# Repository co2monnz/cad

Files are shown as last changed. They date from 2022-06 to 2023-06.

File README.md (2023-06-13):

# co2mon.nz Ventilation Monitor Cases

Inspired by https://github.com/oseiler2/CO2Monitor

## Description

This respoitory contains case designs for CO2 based ventilation monitors
intended for fixed (wall-mounted) use in standard residential, office and
retail type spaces. 

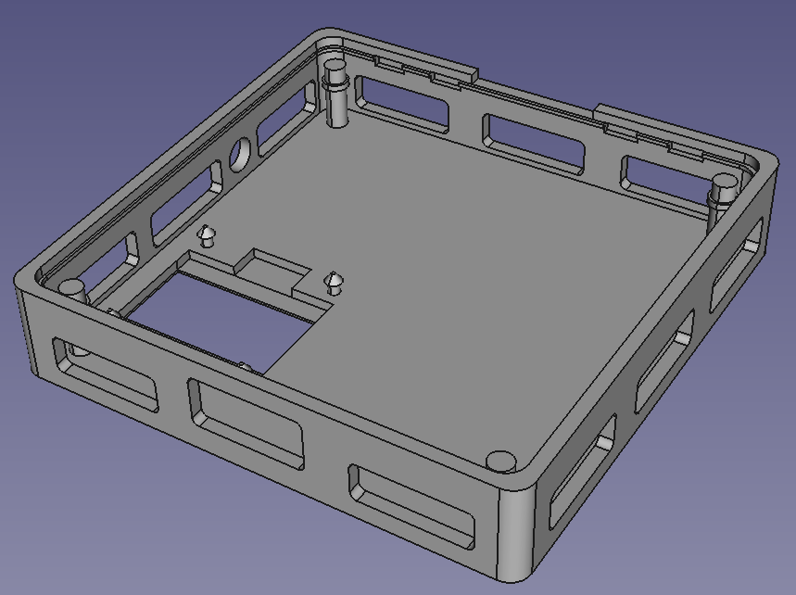
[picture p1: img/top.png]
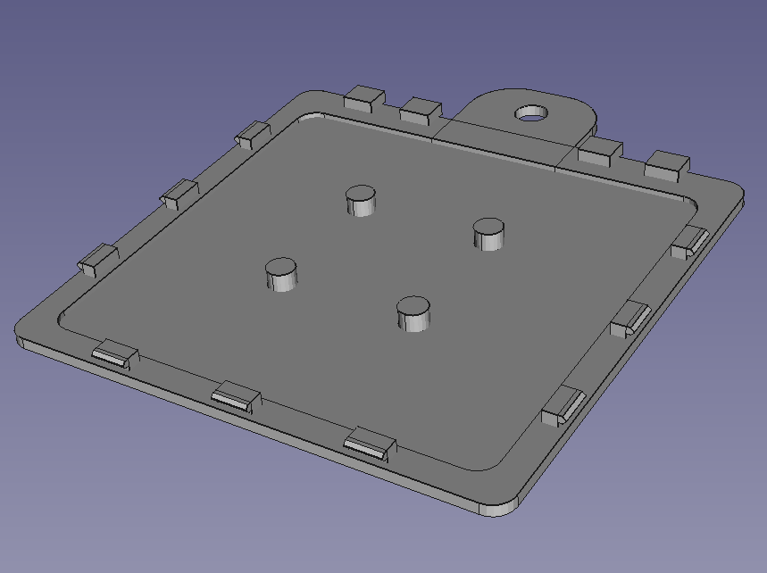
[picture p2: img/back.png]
 

See https://github.com/co2monnz/co2monitor-pcb for a PCB designed to fit within
the 76mm case in this repository.

The other cases/designs are for use with PCBs from the
https://github.com/oseiler2/CO2Monitor repository.

All the cases are 3D printable in PLA or PETG and have been tested to print
reliably using a Prusa i3 MK3S.

## License, Copyright and Reuse

© 2023 [MKMBA Ltd](https://www.mkmba.nz/).

The CAD files and associated data in this repository are available under the
terms of the CC-BY-NC license detailed in the accompanying LICENSE file. 

There doesn't seem to be any perfect way of licensing hadware designs that I've
found yet, so if the CC-BY-NC terms are not suitable for you please get in
touch and I'll generally be fairly wiling to consider other options including
for commercial re-use, etc.

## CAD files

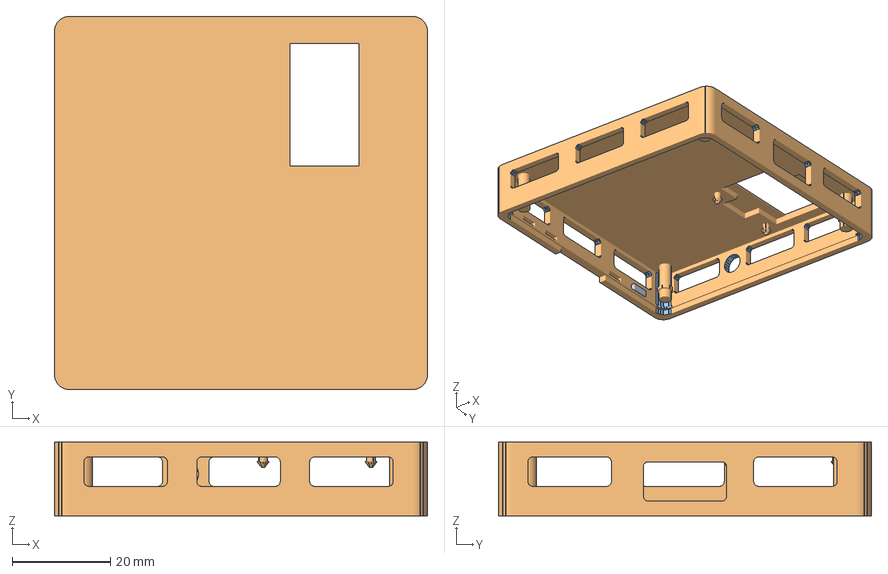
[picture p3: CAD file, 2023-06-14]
76mm-case.FCStd
76.0 x 76.0 x 15.0 mm
BackHanger4
76mm-case
76mm-case (Meshed)

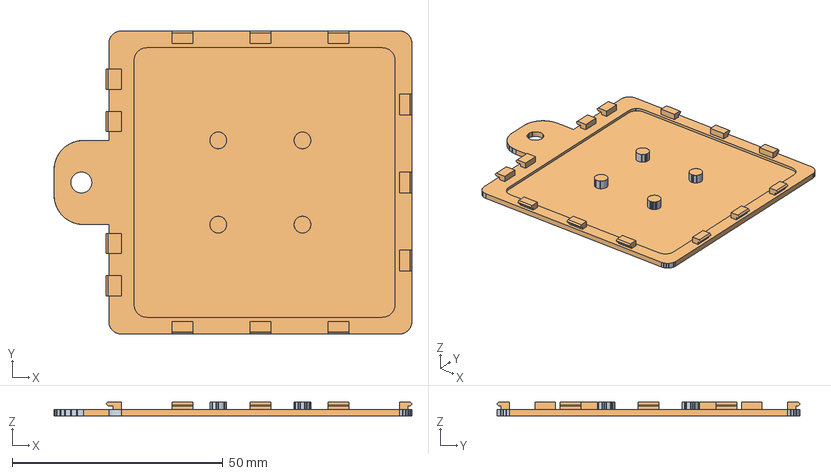
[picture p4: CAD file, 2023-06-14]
76mm-case-back.FCStd
85.0 x 72.0 x 3.40 mm
76mm-case-back
76mm-case-back (Meshed)

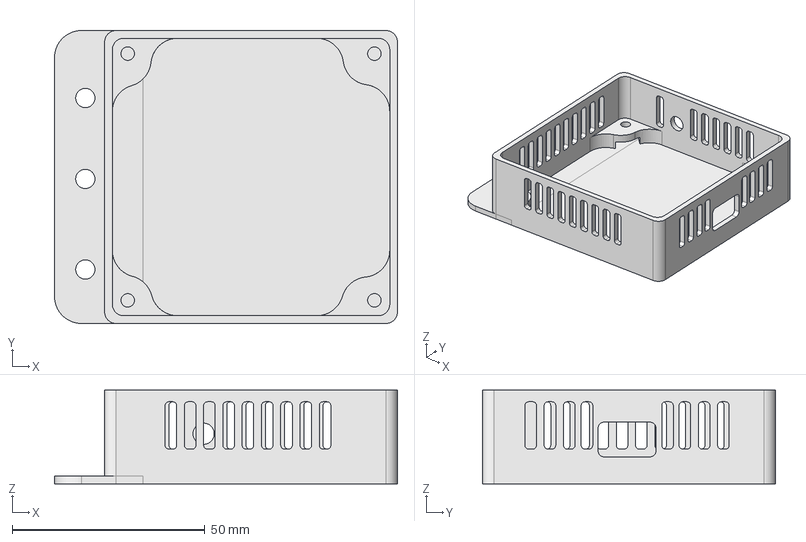
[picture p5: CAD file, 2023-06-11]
7cm-case.FCStd
89.0 x 76.0 x 24.3 mm

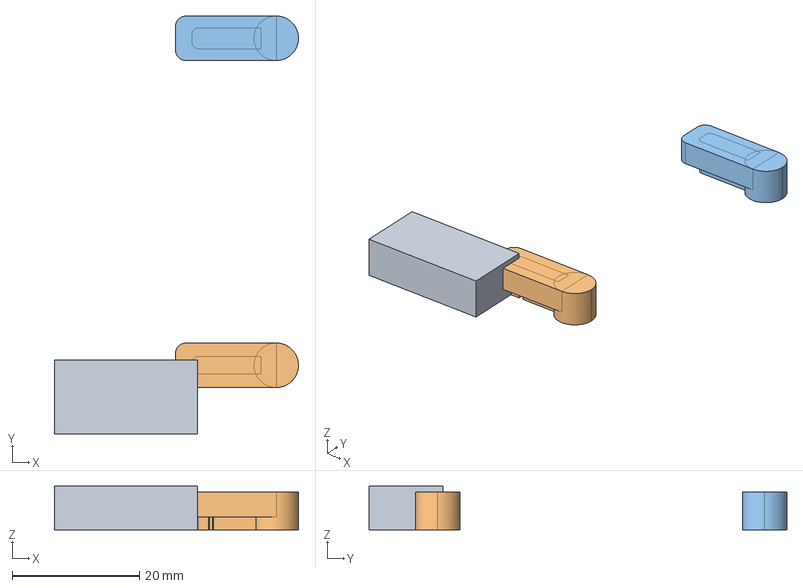
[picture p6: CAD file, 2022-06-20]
mounting-template.FCStd
38.4 x 65.7 x 6.90 mm
MountHoleTemplate
LeftMountHole
RightMountHole

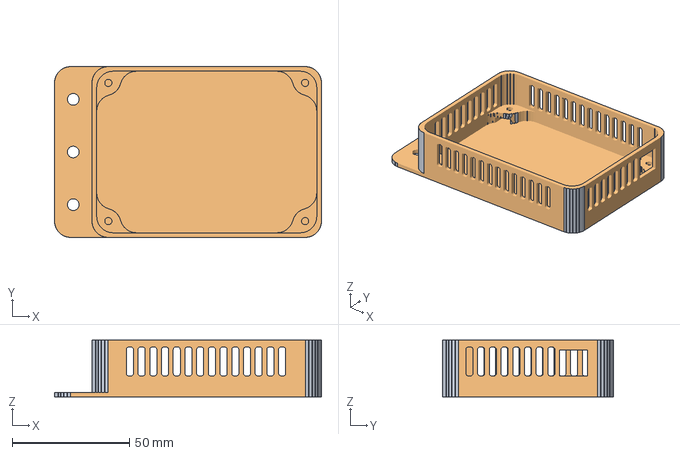
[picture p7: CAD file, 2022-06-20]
case.FCStd
114.0 x 73.0 x 24.3 mm
Case
Case (Meshed)

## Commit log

2022-06-20 First revision of my case design
    [case.FCStd]
2022-06-20 Attempt a mounting holes
    These don't really work well yet.
    [mounting-template.FCStd]
2023-05-22 Initial rough draft of 7cm case/lid
    For https://github.com/co2monnz/co2monitor-pcb
    [7cm-case-lid.FCStd, 7cm-case.FCStd]
2023-06-09 Revised lid/case based on physical tests
    Slightly larger, and with LCD mounting.
    [7cm-case-lid.FCStd, 7cm-case.FCStd]
2023-06-11 Tweak button hole position based on prototypes
    [7cm-case.FCStd]
2023-06-11 Tweak LCD position based on prototypes
    [7cm-case-lid.FCStd]
2023-06-12 Add PCB stands to the back of the cover.
    [7cm-case-lid.FCStd]
2023-06-12 From lid to lid + sides
    [7cm-case-lid.FCStd]
2023-06-12 Rename to reflect new roles and add back
    [76mm-case-back.FCStd, 76mm-case.FCStd, 7cm-case-lid.FCStd]
2023-06-12 Move button hole 'down' 0.5mm
    [76mm-case.FCStd]
2023-06-13 Move hanger/mount to the actual back!
    Bit of a whoopsy in the previous design, putting the mounting holes
    attached to the front. Putting them on the back plate is not ideal,
    since that is only clipping in to the front case portion, so there's a
    risk the main bit falls off the wall leaving only the back attached...
    Revised and increased the size of the clips at the top to be entire
    notches to hopefully take more weight, and added a third clip down each
    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
    [76mm-case-back.FCStd, 76mm-case.FCStd]
2023-06-13 Enlarge back case hanger slots slightly
    For a bit more tolerance.
    [76mm-case.FCStd]
2023-06-14 Return to clip design at top and fix positions
    The previous vs was a few mm off in the tabs on the back - but I didn't
    realise that until I'd already converted back to clips, thiking the tabs
    themselves were the issue.
    [76mm-case-back.FCStd, 76mm-case.FCStd]
